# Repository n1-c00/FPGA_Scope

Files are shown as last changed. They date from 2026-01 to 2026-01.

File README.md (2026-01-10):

# FPGA_Scope
In SMD-soldering there are a lot of very tiny parts with even smaller solder pads. If you really want to solder these parts, you need some sort of magnification. Commonly, a digital microscope is used here. The goal of this repo is to build something like this with as affordable as possible - specifically the CYC1000 from Trenz Electronics, and an OminVision OV5640 Camera.

## Hardware
As stated, the main Chip/DevKit is the Cyclone 10 LP from Altera on the CYC1000.
For this DevKit, I will be designing a daugtherboard which allows the connection of the OV5640 to the FPGA and also adds an HDMI-Port for streaming the Data to a Display.

## Software
For using the scope there will be two possible ways:
1. There is the obvious HDMI-Port poking out from the dautherboard. This will be a HDMI-Source that streams the videofeed to any monitor you'd like.
2. In Addition to this you can connect the FPGA via USB to your PC and run the python file in ./software in order to use it "on the fly". I also would like to add some machine vision features like part detections or
   component-marker-enhancement. This will preferably run on the FPGA or on your local PC. I can't really tell you since this is all WIP...

## Further Links
- [CYC1000 Wiki](https://wiki.trenz-electronic.de/display/PD/TEI0003+Resources)
- [LeFlow](https://github.com/danielholanda/LeFlow)
- [DearPyGUI](https://dearpygui.readthedocs.io/en/latest/)

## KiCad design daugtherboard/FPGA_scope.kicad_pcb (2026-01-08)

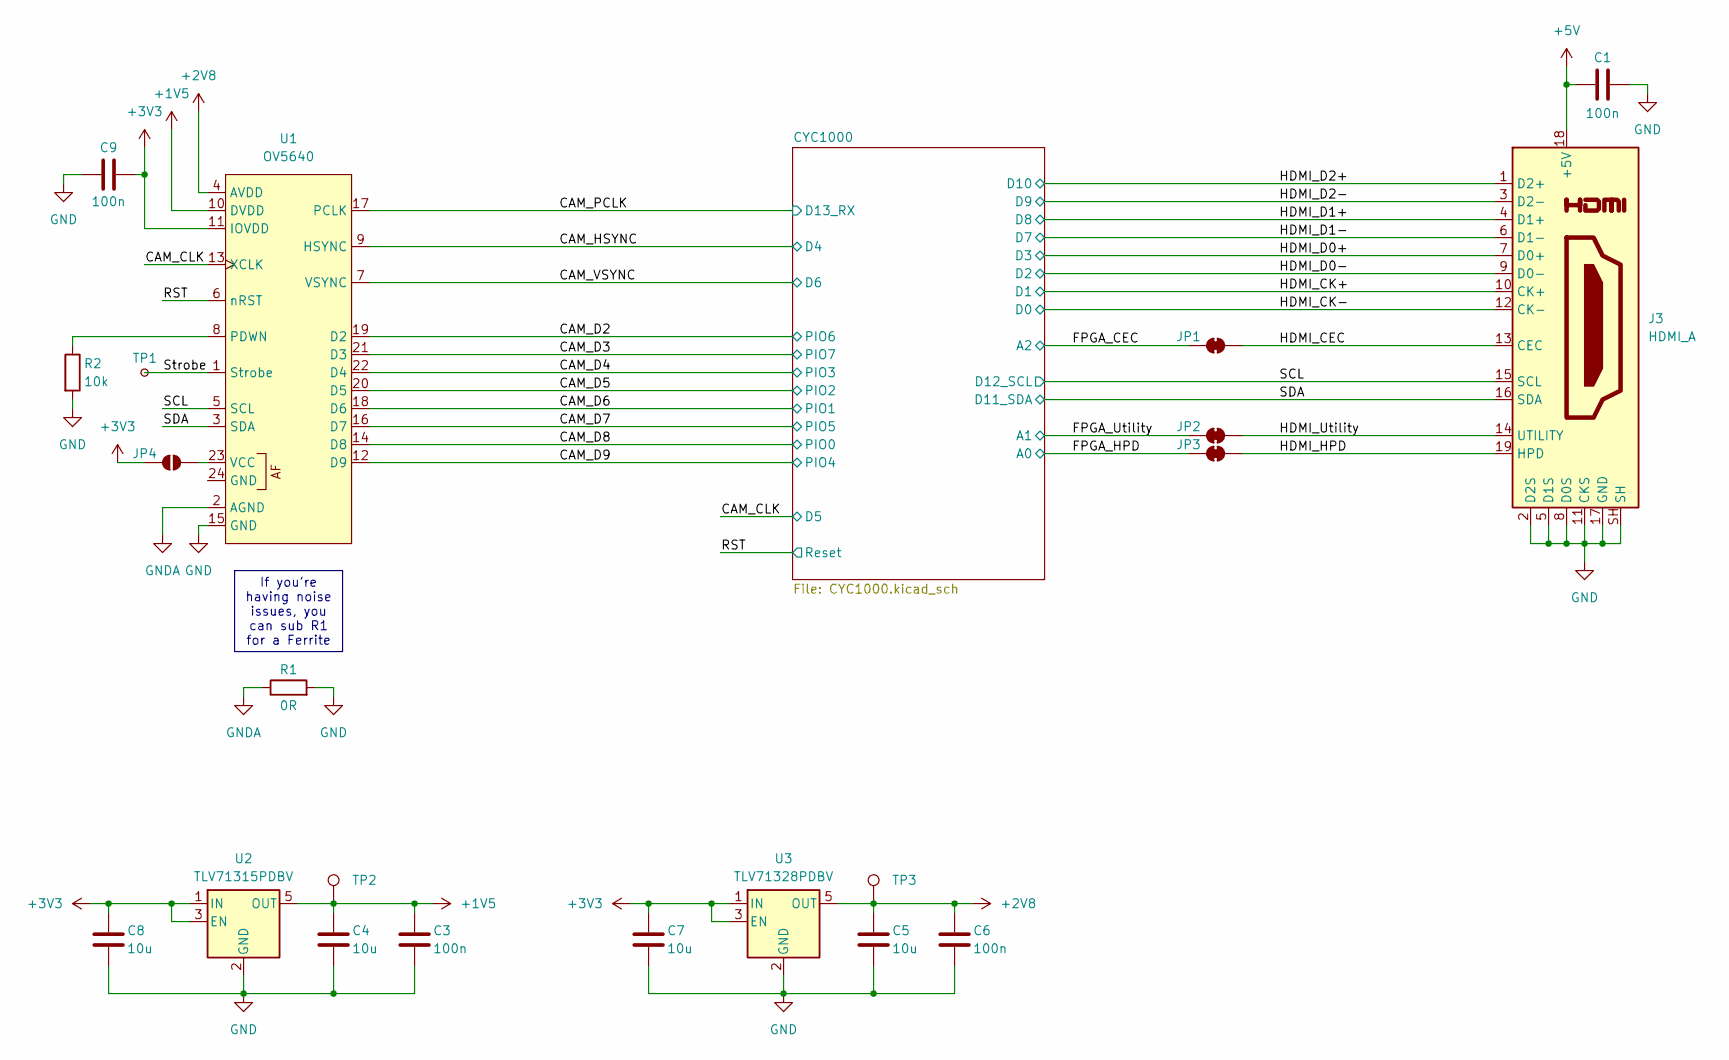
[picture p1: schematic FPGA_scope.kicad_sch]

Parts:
C1, C3, C6, C9: 100n; C_0805_2012Metric
C4, C5, C7, C8: 10u; C_0805_2012Metric
J3: HDMI_A; HDMI_A_Amphenol_10029449-x01xLF_Horizontal
JP1, JP2, JP3: SolderJumper_2_Bridged; SolderJumper-2_P1.3mm_Bridged_RoundedPad1.0x1.5mm
JP4: SolderJumper_2_Open; SolderJumper-2_P1.3mm_Open_RoundedPad1.0x1.5mm
R1: 0R; R_0805_2012Metric
R2: 10k; R_0805_2012Metric
TP1: TestPoint_Small; TestPoint_Pad_D1.5mm
TP2, TP3: TestPoint; TestPoint_Pad_D1.5mm
U1: OV5640; XYECONN_FPC02-S0.5-24AH2.0_24Pin_P0.5mm
U2: TLV71315PDBV; SOT-23-5
U3: TLV71328PDBV; SOT-23-5

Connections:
+1V5: C3.1, C4.1, TP2.1, U1.10 (DVDD), U2.5 (OUT)
+2V8: C5.1, C6.1, TP3.1, U1.4 (AVDD), U3.5 (OUT)
+3V3: C7.1, C8.1, C9.2, JP4.1 (A), U1.11 (IOVDD), U2.1 (IN), U2.3 (EN), U3.1 (IN), U3.3 (EN); also elsewhere on the board
+5V: C1.1, J3.18 (+5V); also elsewhere on the board
/CAM_CLK: U1.13 (XCLK); also elsewhere on the board
/CAM_D2: U1.19 (D2); also elsewhere on the board
/CAM_D3: U1.21 (D3); also elsewhere on the board
/CAM_D4: U1.22 (D4); also elsewhere on the board
/CAM_D5: U1.20 (D5); also elsewhere on the board
/CAM_D6: U1.18 (D6); also elsewhere on the board
/CAM_D7: U1.16 (D7); also elsewhere on the board
/CAM_D8: U1.14 (D8); also elsewhere on the board
/CAM_D9: U1.12 (D9); also elsewhere on the board
/CAM_HSYNC: U1.9 (HSYNC); also elsewhere on the board
/CAM_PCLK: U1.17 (PCLK); also elsewhere on the board
/CAM_VSYNC: U1.7 (VSYNC); also elsewhere on the board
/FPGA_CEC: JP1.1 (A); also elsewhere on the board
/FPGA_HPD: JP3.1 (A); also elsewhere on the board
/FPGA_Utility: JP2.1 (A); also elsewhere on the board
/HDMI_CEC: J3.13 (CEC), JP1.2 (B)
/HDMI_CK+: J3.10 (CK+); also elsewhere on the board
/HDMI_CK-: J3.12 (CK-); also elsewhere on the board
/HDMI_D0+: J3.7 (D0+); also elsewhere on the board
/HDMI_D0-: J3.9 (D0-); also elsewhere on the board
/HDMI_D1+: J3.4 (D1+); also elsewhere on the board
/HDMI_D1-: J3.6 (D1-); also elsewhere on the board
/HDMI_D2+: J3.1 (D2+); also elsewhere on the board
/HDMI_D2-: J3.3 (D2-); also elsewhere on the board
/HDMI_HPD: J3.19 (HPD), JP3.2 (B)
/HDMI_Utility: J3.14 (UTILITY), JP2.2 (B)
/RST: U1.6 (nRST); also elsewhere on the board
/SCL: J3.15 (SCL), U1.5 (SCL); also elsewhere on the board
/SDA: J3.16 (SDA), U1.3 (SDA); also elsewhere on the board
/Strobe: TP1.1, U1.1 (Strobe)
GND: C1.2, C3.2, C4.2, C5.2, C6.2, C7.2, C8.2, C9.1, J3.2 (D2S), J3.5 (D1S), J3.8 (D0S), J3.11 (CKS), J3.17 (GND), J3.SH, R1.2, R2.2, U1.15 (GND), U2.2 (GND), U3.2 (GND); also elsewhere on the board
GNDA: R1.1, U1.2 (AGND)
unnamed: JP4.2 (B), U1.23 (VCC)
unnamed: R2.1, U1.8 (PDWN)

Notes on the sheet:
If you're having noise issues, you can sub R1 for a Ferrite

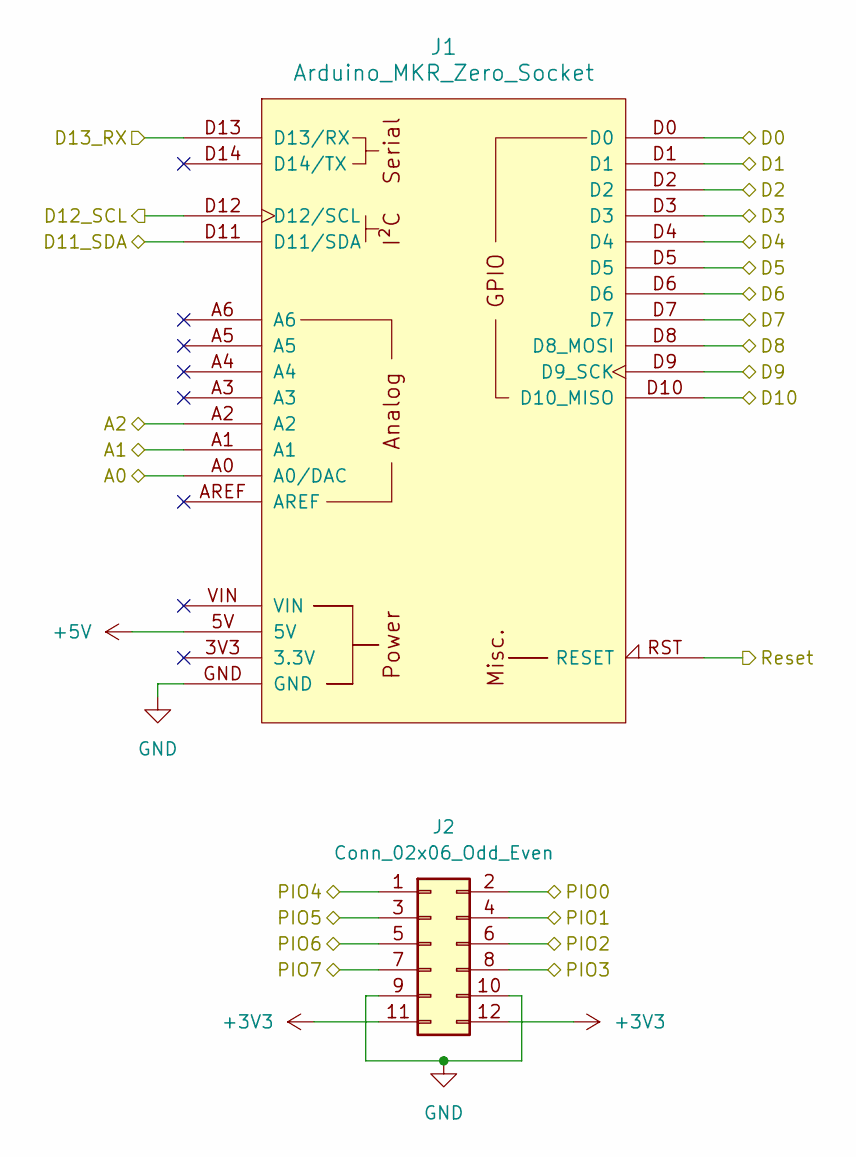
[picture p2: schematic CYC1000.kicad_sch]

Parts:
J1: Arduino_MKR_Zero_Socket
J2: Conn_02x06_Odd_Even; PinSocket_2x06_P2.54mm_Vertical

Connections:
+3V3: J2.11, J2.12; also elsewhere on the board
+5V: J1.5V; also elsewhere on the board
/CAM_CLK: J1.D5; also elsewhere on the board
/CAM_D2: J2.5; also elsewhere on the board
/CAM_D3: J2.7; also elsewhere on the board
/CAM_D4: J2.8; also elsewhere on the board
/CAM_D5: J2.6; also elsewhere on the board
/CAM_D6: J2.4; also elsewhere on the board
/CAM_D7: J2.3; also elsewhere on the board
/CAM_D8: J2.2; also elsewhere on the board
/CAM_D9: J2.1; also elsewhere on the board
/CAM_HSYNC: J1.D4; also elsewhere on the board
/CAM_PCLK: J1.D13 (D13/RX); also elsewhere on the board
/CAM_VSYNC: J1.D6; also elsewhere on the board
/FPGA_CEC: J1.A2; also elsewhere on the board
/FPGA_HPD: J1.A0 (A0/DAC); also elsewhere on the board
/FPGA_Utility: J1.A1; also elsewhere on the board
/HDMI_CK+: J1.D1; also elsewhere on the board
/HDMI_CK-: J1.D0; also elsewhere on the board
/HDMI_D0+: J1.D3; also elsewhere on the board
/HDMI_D0-: J1.D2; also elsewhere on the board
/HDMI_D1+: J1.D8 (D8_MOSI); also elsewhere on the board
/HDMI_D1-: J1.D7; also elsewhere on the board
/HDMI_D2+: J1.D10 (D10_MISO); also elsewhere on the board
/HDMI_D2-: J1.D9 (D9_SCK); also elsewhere on the board
/RST: J1.RST (RESET); also elsewhere on the board
/SCL: J1.D12 (D12/SCL); also elsewhere on the board
/SDA: J1.D11 (D11/SDA); also elsewhere on the board
GND: J1.GND, J2.9, J2.10; also elsewhere on the board

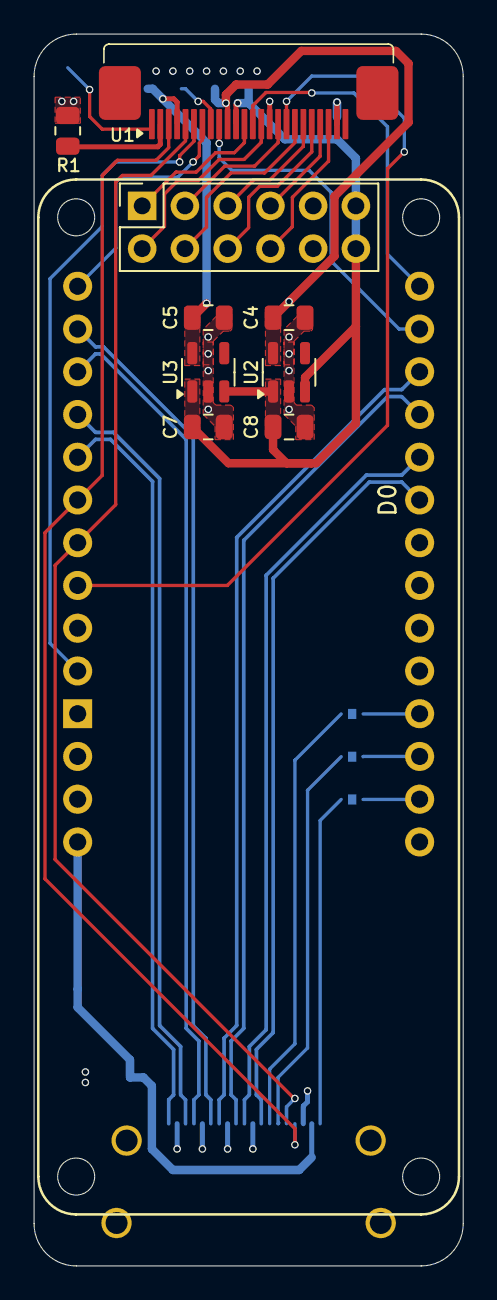
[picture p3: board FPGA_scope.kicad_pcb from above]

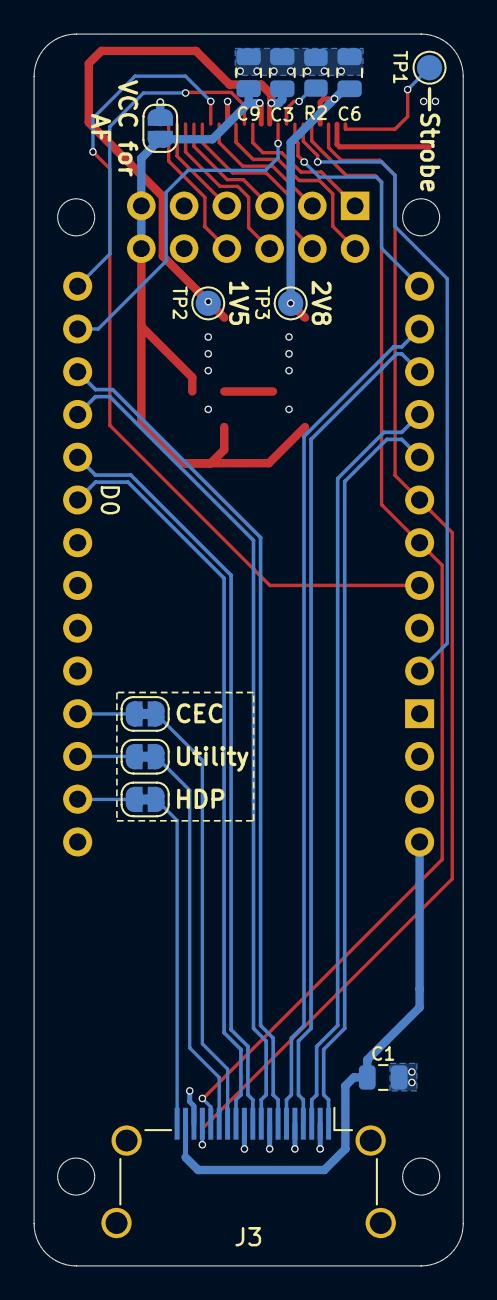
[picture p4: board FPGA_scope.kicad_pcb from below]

Board: 4 copper layers, 25.5 x 73.2 mm, 23 parts (13 on the bottom side), 38 nets.

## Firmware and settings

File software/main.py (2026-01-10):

import array
import dearpygui.dearpygui as gui
import cv2
import numpy as np
import serial
import serial.tools.list_ports

# Standard baud rates (widely supported)
STANDARD_BAUDS = [1200, 2400, 4800, 9600, 19200, 38400, 57600, 115200]
# High-speed rates (platform/hardware dependent)
HIGH_SPEED_BAUDS = [230400, 460800, 921600, 1000000, 1500000, 2000000]

cam = cv2.VideoCapture(0)
video_data = array.array('f')

frame_width = 100
frame_height = 100

serial_baud = None
serial_port = None


def test_baud_rate(port, baudrate):
    """Test if baud rate works with device"""
    try:
        test_ser = serial.Serial(port, baudrate, timeout=1)
        
        # Send test command
        test_ser.write(b'AT\r\n')
        response = test_ser.readline()
        
        test_ser.close()
        
        return len(response) > 0
    except:
        return False

def serial_find_ports():
    available_ports = []
    for port in serial.tools.list_ports.comports():
        available_ports.append(port)

    return available_ports

def serial_find_optimal_baudrate(port, test_bauds=None):
    #Find highest working baud rate
    if test_bauds is None:
        test_bauds = STANDARD_BAUDS + HIGH_SPEED_BAUDS
    
    working_bauds = []
    
    for baud in sorted(test_bauds):
        if test_baud_rate(port, baud):
            working_bauds.append(baud)
    
    return max(working_bauds) if working_bauds else None


def _update_video():
    ###----OpenCV-based Demo with PC-Camera----###
    global video_data
    global frame_width
    global frame_height

    # Capture one frame
    ret, frame = cam.read()

    frame_width = int(cam.get(cv2.CAP_PROP_FRAME_WIDTH))
    frame_height = int(cam.get(cv2.CAP_PROP_FRAME_HEIGHT))

    if ret:
        data = np.flip(frame, 2) #convert from BGR to RGB
        data = data.ravel() #flatten the incoming camera data into a 1d array
        data = np.asarray(data, dtype='f')

        video_data = np.true_divide(data, 255.0)
    else:
        print("Failed to capture image!")

gui.create_context()

_update_video()

with gui.texture_registry():
   gui.add_raw_texture(width=frame_width, height=frame_height, default_value=video_data, format=gui.mvFormat_Float_rgb, tag="video_feed", label="video")

#the viewport is the "window" which we create here
gui.create_viewport(title='FPGA_Scope', width=frame_width+100, height=frame_height+100)
gui.setup_dearpygui()

#create the main window of the application
with gui.window(tag="Primary Window"):
    
    ###----menu bar----###
    with gui.menu_bar(label="top_menu"):
        #ToDo: Add settings for the gui itself (dark-mode, light-mode, ...)
        # with gui.menu(label="Settings"):
        #     ...
        with gui.menu(label="Connection"):
            gui.add_menu_item(label="Start Connection...")

            with gui.menu(label="Port:"):
                for item in serial_find_ports():
                    gui.add_menu_item(label=item)
            with gui.menu(label="Baudrate:"):

                gui.add_menu_item(label="Auto")
                for item in STANDARD_BAUDS + HIGH_SPEED_BAUDS:
                    gui.add_menu_item(label= str(item))

        with gui.menu(label="Machine-Vision"):
            gui.add_menu_item(label="local models:")
            gui.add_menu_item(label="FPGA models:")

        gui.add_menu_item(label="About")
        


    ###----actual video feed----###
    gui.add_image("video_feed")


gui.show_viewport()
#set the window as the actual primary window
gui.set_primary_window("Primary Window", True)

#render loop
while gui.is_dearpygui_running():
    # insert here any code you would like to run in the render loop
    # you can manually stop by using stop_dearpygui()

    #get new data from the camera and update the data for the gui accordingly
    _update_video()
    gui.set_value("video_feed", video_data)
    gui.render_dearpygui_frame()


#cleanup
gui.destroy_context()
cam.release()

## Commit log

2026-01-03 First Drawup of Schematic and PCB
    [CYC1000.kicad_sch, FPGA_scope.kicad_pcb, FPGA_scope.kicad_sch]
2026-01-08 start of PC Software
    [CYC1000.kicad_sch, FPGA_scope.kicad_pcb, FPGA_scope.kicad_sch]
2026-01-10 Tested GUI-framework with cv2 video-stream
